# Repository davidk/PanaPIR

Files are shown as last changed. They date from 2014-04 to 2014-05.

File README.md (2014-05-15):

# Panasonic PIR breakout board

This is a Panasonic PIR breakout board. It breaks out their TO-5 sensors onto 0.1"/2.54mm pitch headers, for use with a solderless breadboard.

Here is what it looks like currently:

Top (alongside the EKMC1601111):

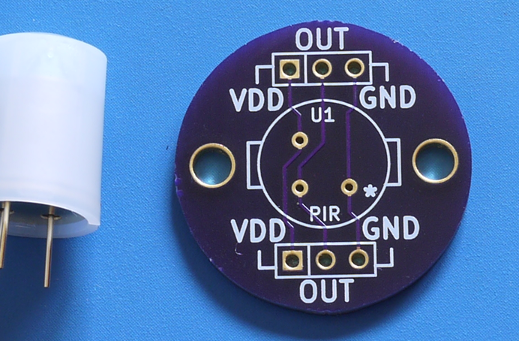
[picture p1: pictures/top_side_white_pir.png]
Panasonic PIR breakout board - top


Rear (note the filled in gold area on one pin of the PIR, it goes with the \* on the board and denotes ground):

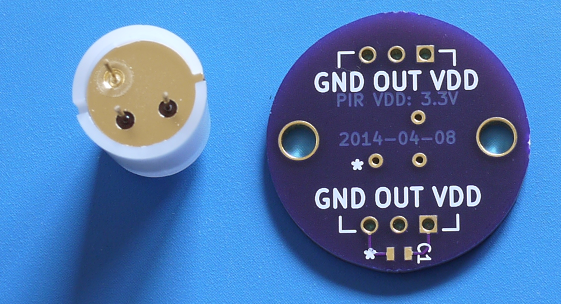
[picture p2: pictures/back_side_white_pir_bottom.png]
Panasonic PIR breakout board - bottom


## Fabrication

The simplest way is to just [click through to this shared project on OSHPark's site](http://oshpark.com/shared_projects/VIIMKRcy). You'll get three boards with purple soldermask.

If you prefer using your own CNC/mill/board house, just grab the Gerber files and KiCAD source and bobs (nearly) your uncle. If you really are going to use a CNC/mill/etch, it might be ideal to drop a polygon fill on both sides to minimize the amount of copper that needs to be removed.

### Bill of Materials

Pick a sensor (these have been verified to fit on this breakout):

| Model | Vendor |
| --- | --- |
| EKMB1303112 | [Mouser](http://www.mouser.com/Search/Refine.aspx?Keyword=EKMB1303112) |
| EKMC1601111 | [Digikey](http://www.digikey.com/product-search/en?WT.z_header=search_go&lang=en&site=us&keywords=EKMC1601111) |

You'll also need a strip of 0.1"/2.54mm header, but this is optional (since you may use wire to permanently 
install the breakout later).

| Quantity | Description/Vendor |
| --- | --- |
| 1 | 36-pin header: [Mouser: 649-68004-236](http://www.mouser.com/Search/Refine.aspx?Keyword=649-68004-236) / Alternative (3-pin, untested!): [Mouser: 571-1031853](http://www.mouser.com/Search/Refine.aspx?Keyword=571-1031853) |

## Licensing

CC0 1.0 Universal (the LICENSE file has more details)

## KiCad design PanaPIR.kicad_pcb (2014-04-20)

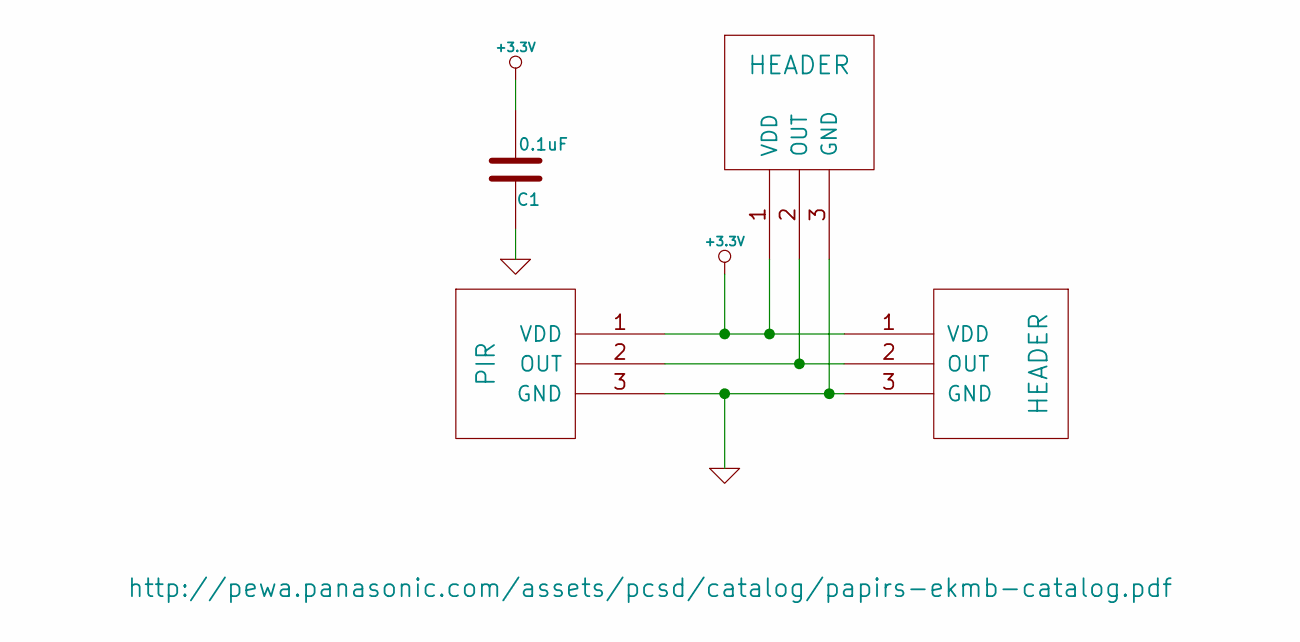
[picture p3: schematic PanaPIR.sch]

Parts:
C1: 0.1uF
P1, P2: HEADER
U1: PIR

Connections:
+3.3V: C1.2, P1.1 (VDD), P2.1 (VDD), U1.1 (VDD)
GND: C1.1, P1.3 (GND), P2.3 (GND), U1.3 (GND)
unnamed: P1.2 (OUT), P2.2 (OUT), U1.2 (OUT)

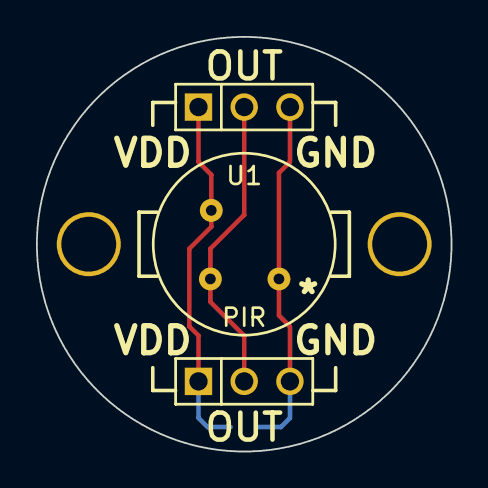
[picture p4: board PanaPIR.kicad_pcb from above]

Board: 2 copper layers, 23.0 x 23.0 mm, 6 parts (1 on the bottom side), 3 nets.

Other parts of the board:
1PIN, 1PIN#2: P***; 3mm_mounting

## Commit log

2014-03-30 Add KiCAD files from previous git repository
    This still retains the short git commit hash written on the back
    of the PCB (mask layer) from that repository.
    [PanaPIR.kicad_pcb, PanaPIR.sch]
2014-03-31 Add board image
2014-03-31 Add picture
    Closes #2
    This will likely redone in the future with the actual sensor in the photo.
2014-03-31 Add KiCAD generated gerbers.
    These gerbers were used for fabrication with OSHPark, and
    have export parameters tuned to their requirements.
    closes #1
    [PanaPIR-B_Cu.gbl, PanaPIR-B_Mask.gbs, PanaPIR-B_SilkS.gbo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]
2014-03-31 Generate a zip file of gerbers for upload to OSHPark
    Genereated from files in commit: 5116fca
2014-04-20 Make PCB more compatible with breadboards
    [PanaPIR.kicad_pcb]
2014-04-20 2014-04-08 production gerbers
    [PanaPIR-B_Cu.gbl, PanaPIR-B_Mask.gbs, PanaPIR-B_SilkS.gbo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]
2014-04-20 Zipped gerbers from eabde8d
2014-04-20 Add 0603 decoupling cap and better spacing for breadboards
    600 mil center drill distance from top to bottom for PTH headers.
    [PanaPIR.kicad_pcb, PanaPIR.sch]
2014-04-29 Remove older board photo and add new ones
2014-04-29 Update photos with current breakout
2014-04-29 More board notes
